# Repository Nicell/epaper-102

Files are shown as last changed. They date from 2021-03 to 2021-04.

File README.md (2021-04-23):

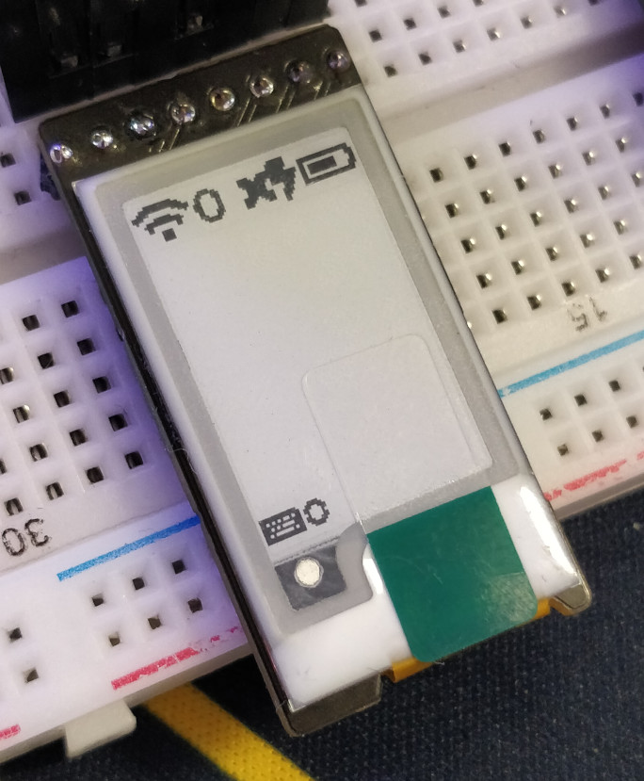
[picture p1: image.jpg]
Display Module


# 1.02 inch e-ink Display Module

This is an open-source e-ink or e-paper display module that's only 19.5mm x 38.5mm.

This module is made for the Good Display GDEW0102T4 1.02 inch e-ink display, which [Waveshare resells](https://www.waveshare.com/product/displays/e-paper/epaper-3/1.02inch-e-paper-module.htm). This is a slimmed down version of the Waveshare module without the logic translation circuitry, which means this must be run at 3.3V.

## Ordering from JLCPCB and LCSC

This module is ready to be (almost fully) assembled. You'll need three files, `gerbers.zip`, `epaper-102-bom.csv`, and `epaper-102-bottom-pos.xlsx`.

1. Go to [JLCPCB.com](https://cart.jlcpcb.com/quote?orderType=1) quote page
2. Upload the `gerbers.zip` file to the quote page
3. Select any options you would like. PCB Color must be Green or Black and thickness must be 1.6mm
4. Check SMT Assembly under the PCB section
5. Select "Assemble bottom side"
6. Agree to terms and click Confirm
7. Add `epaper-102-bom.csv` as the BOM file and `epaper-102-bottom-pos.xlsx` as the CPL file on this page. Click Next
8. All parts on this page should be found automatically. Click next
9. Confirm placements look good (they should be fine) and click "Save to Cart"
10. Checkout when you're ready

## Ordering the display

You'll also need the actual 1.02 inch e-ink display to put in the module. You can order them from one of the following places:

 - [Waveshare](https://www.waveshare.com/product/displays/e-paper/epaper-3/1.02inch-e-paper.htm)
 - [AliExpress](https://www.aliexpress.com/item/4000504958641.html)
 - [Alibaba](https://goodlcd.en.alibaba.com/product/62454456237-807321088/1_inch_small_epaper_mini_eink_display_for_smart_watch.html)

I found AliExpress to be the cheapest in terms of display price and shipping, but you should check for yourself.

## Assembling

Once all your parts have arrived, you'll need to insert the display.

#### Connecting the display

Pull up on the FFC connector lever, and insert the display into the connector with the gold pins facing away from the PCB. Once it's all the way in, push the lever back down to lock it in place.

Now your module is all ready to go. You may want to use a bit of tape or adhesive to make sure the display sticks in place.

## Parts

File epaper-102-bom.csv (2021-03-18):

Item | Qty | Reference(s) | Value | LibPart | Footprint | Datasheet | LCSC
1 | 1 | C1 | 4.7uF | Device:C_Small | Capacitor_SMD:C_0402_1005Metric | ~ | C23733
2 | 12 | C2, C3, C4, C5, C6, C7, C8, C9, C10, C11, C13, C15 | 1uF | Device:C_Small | Capacitor_SMD:C_0402_1005Metric | ~ | C52923
3 | 2 | C12, C14 | 2.2uF | Device:C_Small | Capacitor_SMD:C_0603_1608Metric | ~ | C23630
4 | 1 | D1 | D | Device:D_Schottky_Small | Diode_SMD:D_SOD-123 | ~ | C8598
5 | 1 | J1 | Conn_01x30_Female | Connector:Conn_01x30_Female | Connector_FFC-FPC:Hirose_FH12-30S-0.5SH_1x30-1MP_P0.50mm_Horizontal | ~ | C262294
6 | 1 | J2 | Conn_01x08_Female | Connector:Conn_01x08_Female | Connector_PinHeader_2.00mm:PinHeader_1x08_P2.00mm_Vertical | ~
7 | 2 | C16, C17 | 100nF | Device:C_Small | Capacitor_SMD:C_0402_1005Metric | ~ | C1525

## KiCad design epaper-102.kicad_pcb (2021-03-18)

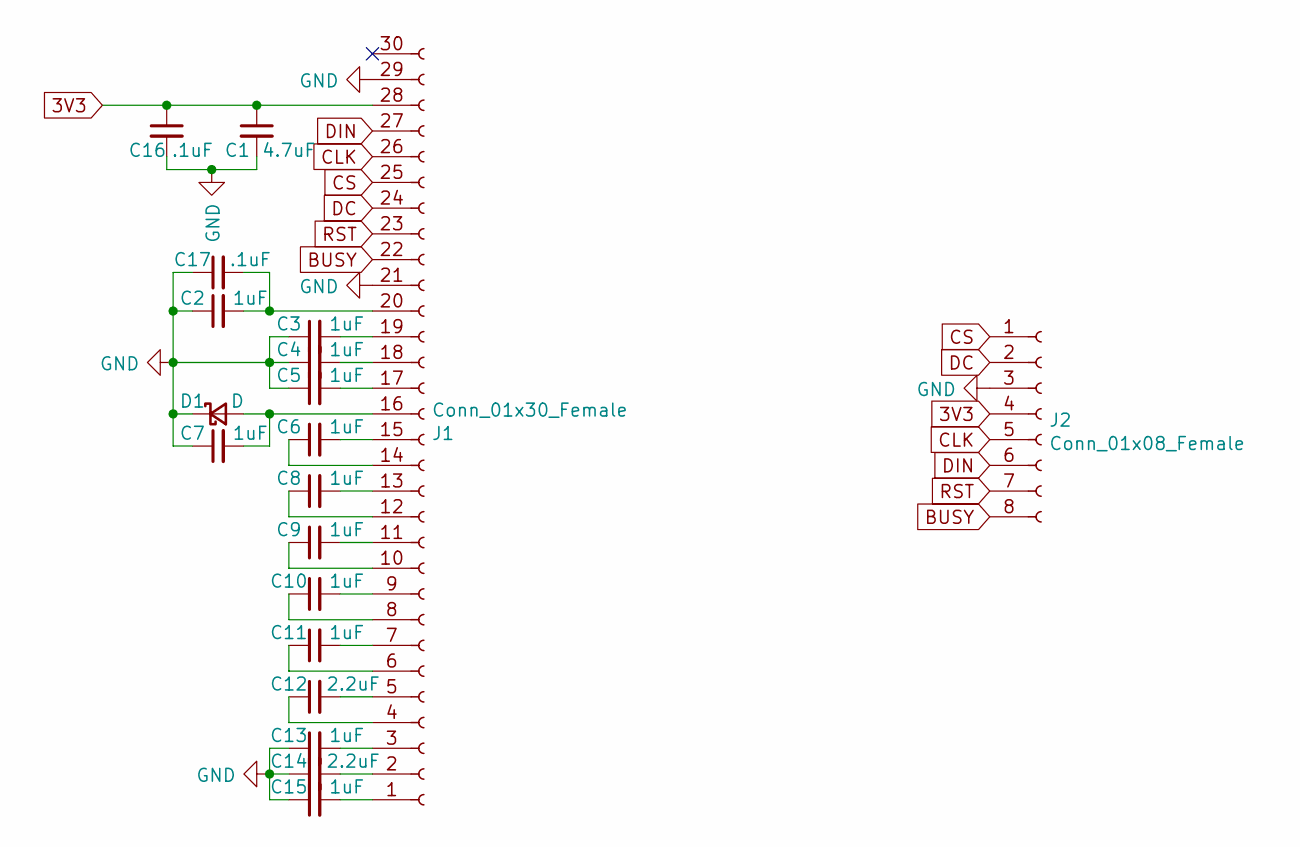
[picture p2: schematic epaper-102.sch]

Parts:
C1: 4.7uF; C_0402_1005Metric; LCSC C23733
C2, C3, C4, C5, C6, C7, C8, C9, C10, C11, C13, C15: 1uF; C_0402_1005Metric; LCSC C52923
C12, C14: 2.2uF; C_0603_1608Metric; LCSC C23630
C16, C17: .1uF; C_0402_1005Metric; LCSC C1525
D1: D; D_SOD-123; LCSC C8598
J1: Conn_01x30_Female; Hirose_FH12-30S-0.5SH_1x30-1MP_P0.50mm_Horizontal; LCSC C262294
J2: Conn_01x08_Female; PinHeader_1x08_P2.54mm_Vertical

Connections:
3V3: C1.1, C16.1, J1.28, J2.4
BUSY: J1.22, J2.8
CLK: J1.26, J2.5
CS: J1.25, J2.1
DC: J1.24, J2.2
DIN: J1.27, J2.6
GND: C1.2, C2.1, C3.1, C4.1, C5.1, C7.1, C13.1, C14.1, C15.1, C16.2, C17.1, D1.1 (K), J1.21, J1.29, J2.3
unnamed: C3.2, J1.19
unnamed: C4.2, J1.18
unnamed: C5.2, J1.17
unnamed: C6.1, J1.14
unnamed: C6.2, J1.15
unnamed: C7.2, D1.2 (A), J1.16
unnamed: C8.1, J1.12
unnamed: C8.2, J1.13
unnamed: C9.1, J1.10
unnamed: C9.2, J1.11
unnamed: C10.1, J1.8
unnamed: C10.2, J1.9
unnamed: C11.1, J1.6
unnamed: C11.2, J1.7
unnamed: C12.1, J1.4
unnamed: C12.2, J1.5
unnamed: C13.2, J1.3
unnamed: C14.2, J1.2
unnamed: C15.2, J1.1
unnamed: C2.2, C17.2, J1.20
RST: J1.23, J2.7

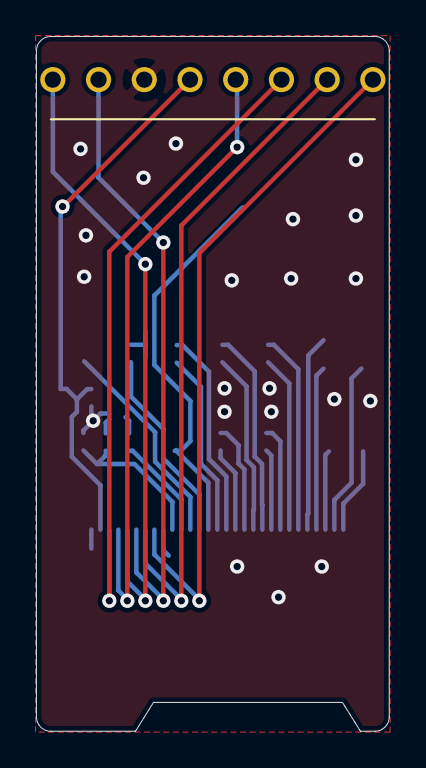
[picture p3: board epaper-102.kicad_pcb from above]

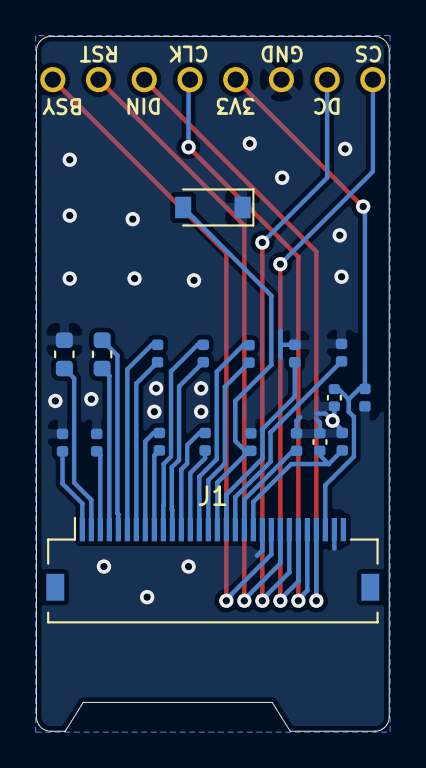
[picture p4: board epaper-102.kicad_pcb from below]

Board: 2 copper layers, 19.6 x 38.6 mm, 20 parts (20 on the bottom side), 28 nets.

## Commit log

2021-04-22 Remove FCC soldering part
2021-04-23 Update position for FFC to match JLC SMT
    [epaper-102-bottom-pos.xlsx]
